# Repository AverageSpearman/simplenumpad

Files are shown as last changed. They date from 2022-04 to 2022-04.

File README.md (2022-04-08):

# simplenumpad
A very basic, hacked together mechanical numpad.

## Introduction

This was made with the goal of having a numpad to go with a mechanical keyboard lacking one.
Since I didn't want to bother with either buying a kit or going to a manufacturer to get a pcb, this is made using basically as few new parts as possible.
Most of the parts that aren't the electronics are just random garbage around the house.

## Parts List
Because this project doesn't use a PCB, all of the parts listed are through-hole components (THT).

|Part |Quantity |
|:--: |:---|
|Cherry MX Switches | 17 |
|1n4148 Diode | 17 |
|Arduino Pro Micro  | 1 |

That's pretty much it. You can even skip the diodes if you want to put in the anti-ghosting features in software. Stabilizers for the larger keys are optional.

## Layout
The layout is done in KiCad, but only because it's easy to get footprints for different kinds of mechanical switches, and print the design.
**The PCB design is used mainly as a wiring and layout guide. It is not meant to be manufactured and is not made to manufacturing specifications or common practice.**

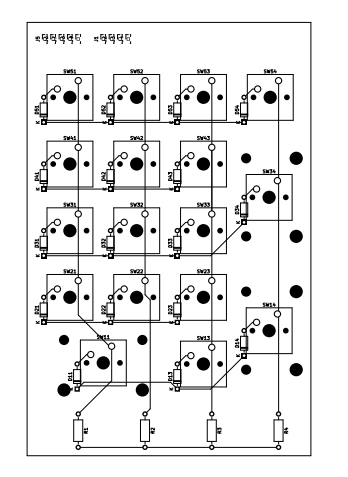
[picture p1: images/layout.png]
Printed Layout


## Assembly

### Circuit Board

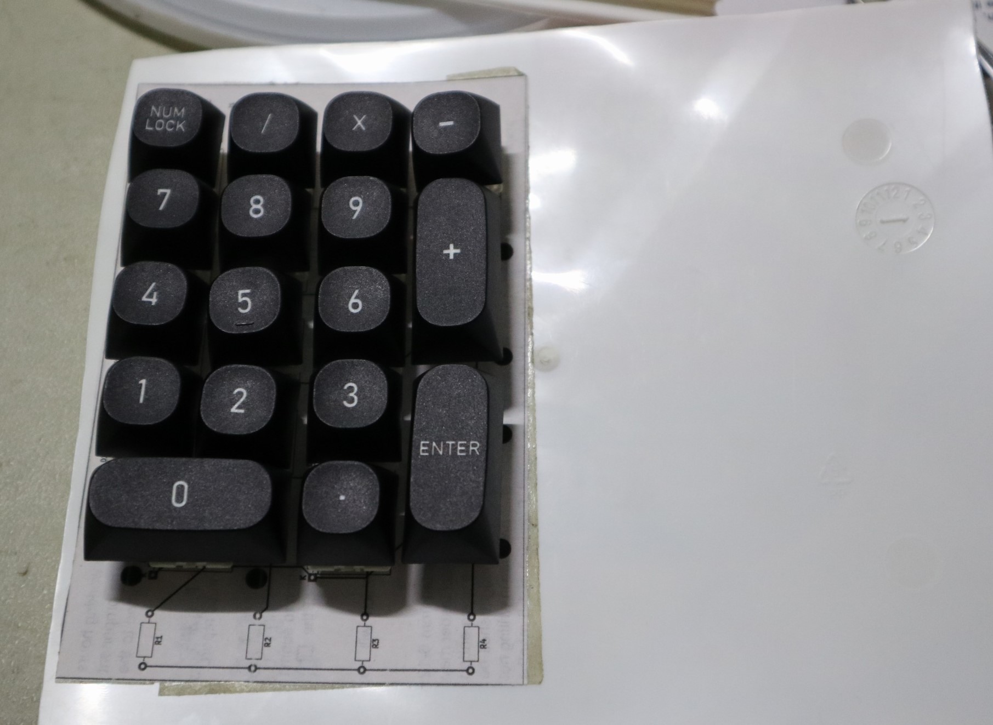
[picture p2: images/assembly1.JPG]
Switches and Caps in place


The first step is to punch, drill, or otherwise make the holes to mount the switches. You'll want to use PCB mount switches if you can, but I got away with plate-mounted switches, since they still at least have that big peg in the middle. These switches will more or less **be stuck where they are after the build, for the most part.** This *is* a really hacky, dirty way of doing it, but it is cheap. Jam the switches in, and then use hot glue or some other adhesive should you need it. You can put your keycaps on as well, if you want.

### Wiring

Use the schematic and layout as a guide when wiring the rows and columns. Make sure all of your diodes are facing the same direction (If you get them all backwards you should be able to fix it in software, but only if they're all backwards).

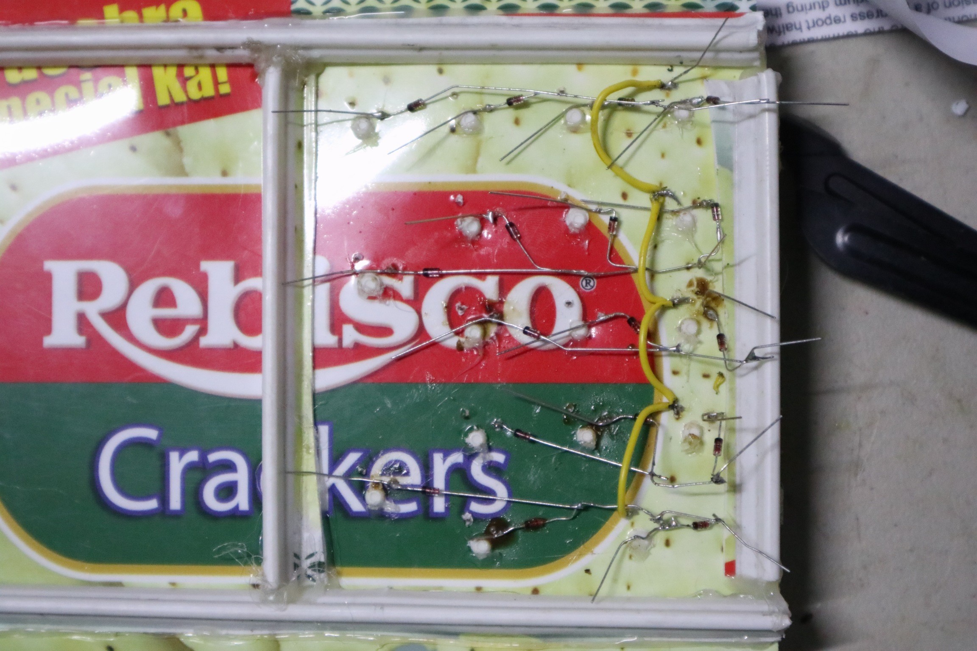
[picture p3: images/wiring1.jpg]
Wiring, the diode rows and one column

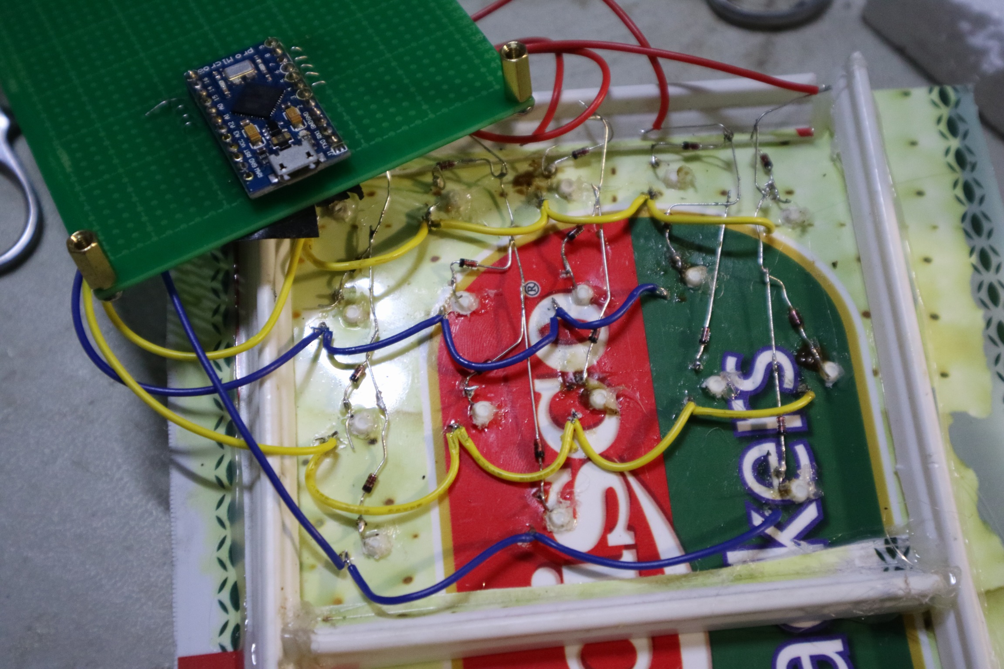
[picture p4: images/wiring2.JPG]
Wring, completed


## Code

This uses the SET library by RobTillaart ([Link](https://github.com/RobTillaart/SET)).
The code energizes columns and reads rows in a matrix, then puts them in sets and gets the difference to figure out which keys are newly pressed or released. The code will only press and release the keys as needed.

## Finished!

That's about it. Good luck!

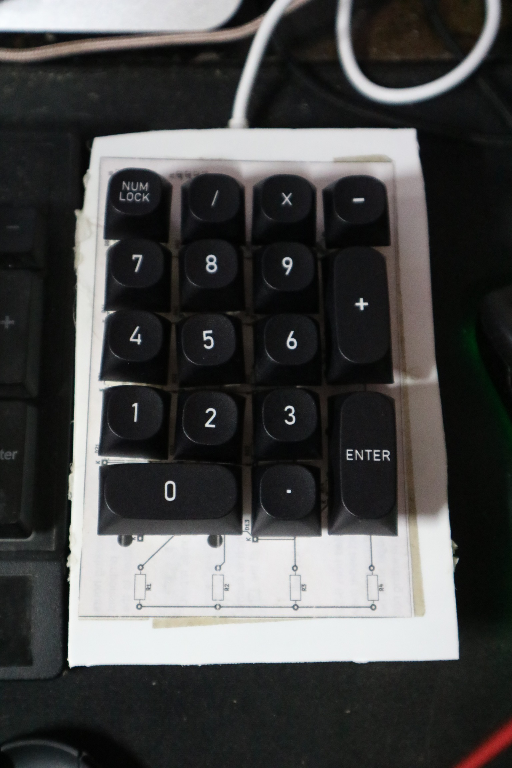
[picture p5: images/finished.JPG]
Finished numpad


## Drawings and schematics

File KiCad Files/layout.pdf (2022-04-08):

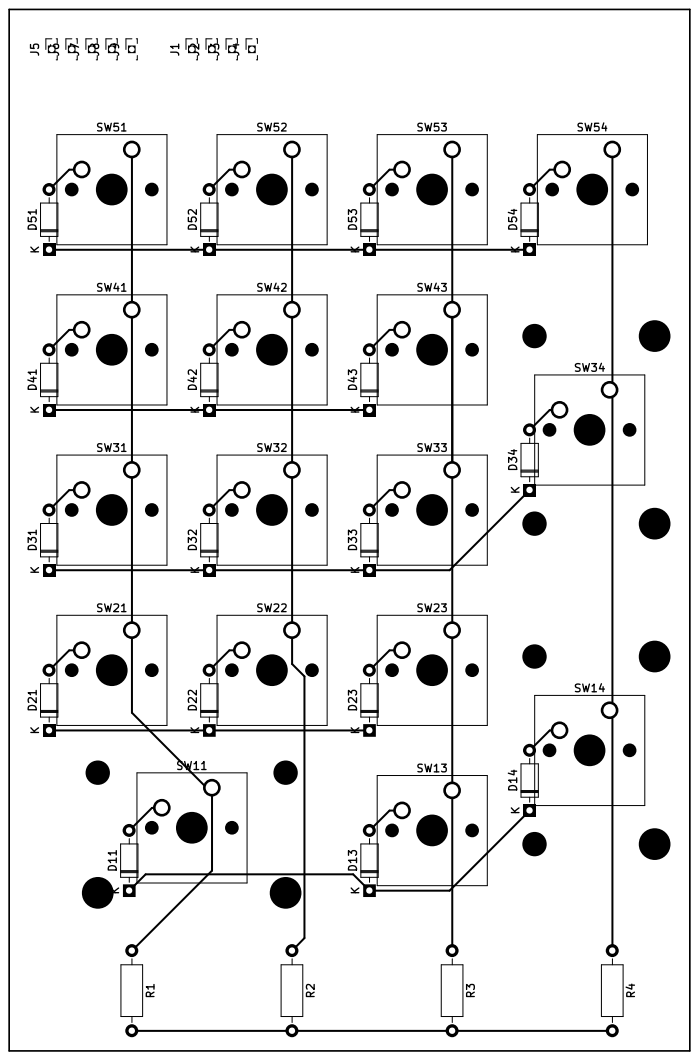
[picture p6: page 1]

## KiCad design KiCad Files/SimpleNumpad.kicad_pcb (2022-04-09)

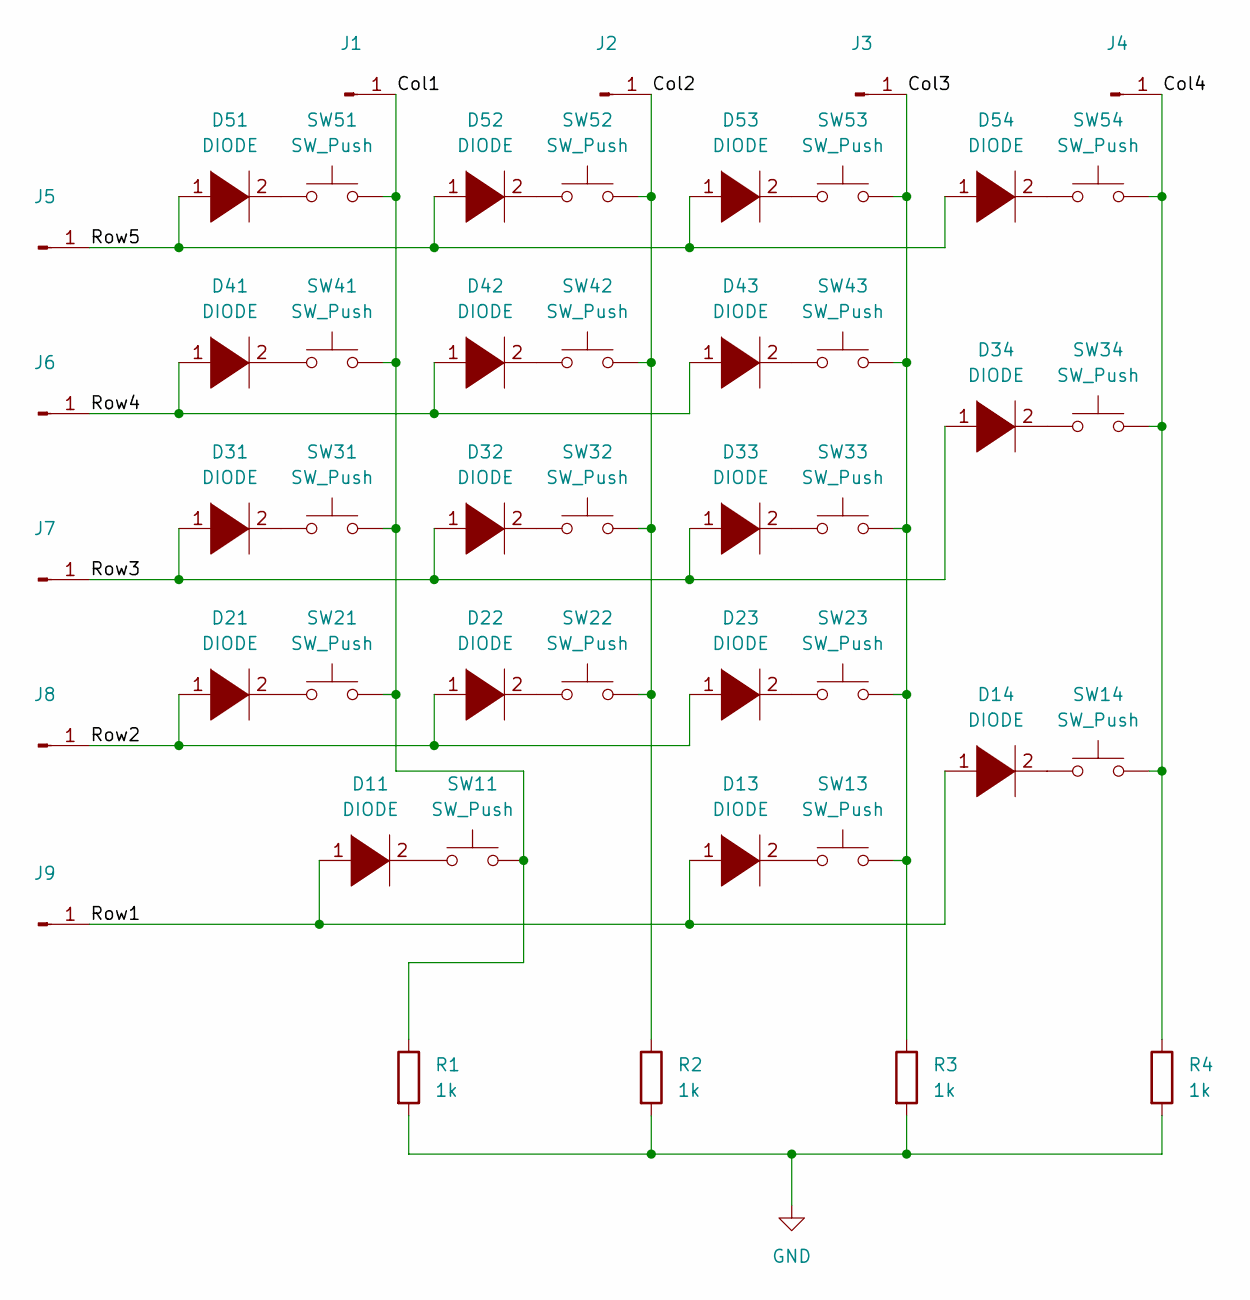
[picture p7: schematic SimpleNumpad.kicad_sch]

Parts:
D11, D13, D14, D21, D22, D23, D31, D32, D33, D34, D41, D42, D43, D51, D52, D53, D54: DIODE; D_DO-35_SOD27_P7.62mm_Horizontal
J1, J2, J3, J4, J5, J6, J7, J8, J9: (no value)
R1, R2, R3, R4: 1k; R_Axial_DIN0207_L6.3mm_D2.5mm_P10.16mm_Horizontal
SW11: SW_Push; SW_Cherry_MX_2.00u_PCB
SW13, SW21, SW22, SW23, SW31, SW32, SW33, SW41, SW42, SW43, SW51, SW52, SW53, SW54: SW_Push; SW_Cherry_MX_1.00u_PCB
SW14, SW34: SW_Push; SW_Cherry_MX_2.00u_Vertical_PCB

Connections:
/Col1: J1.1, R1.1, SW11.1, SW21.1, SW31.1, SW41.1, SW51.1
/Col2: J2.1, R2.1, SW22.1, SW32.1, SW42.1, SW52.1
/Col3: J3.1, R3.1, SW13.1, SW23.1, SW33.1, SW43.1, SW53.1
/Col4: J4.1, R4.1, SW14.1, SW34.1, SW54.1
/Row1: D11.1 (K), D13.1 (K), D14.1 (K), J9.1
/Row2: D21.1 (K), D22.1 (K), D23.1 (K), J8.1
/Row3: D31.1 (K), D32.1 (K), D33.1 (K), D34.1 (K), J7.1
/Row4: D41.1 (K), D42.1 (K), D43.1 (K), J6.1
/Row5: D51.1 (K), D52.1 (K), D53.1 (K), D54.1 (K), J5.1
GND: R1.2, R2.2, R3.2, R4.2
unnamed: D11.2 (A), SW11.2
unnamed: D13.2 (A), SW13.2
unnamed: D14.2 (A), SW14.2
unnamed: D21.2 (A), SW21.2
unnamed: D22.2 (A), SW22.2
unnamed: D23.2 (A), SW23.2
unnamed: D31.2 (A), SW31.2
unnamed: D32.2 (A), SW32.2
unnamed: D33.2 (A), SW33.2
unnamed: D34.2 (A), SW34.2
unnamed: D41.2 (A), SW41.2
unnamed: D42.2 (A), SW42.2
unnamed: D43.2 (A), SW43.2
unnamed: D51.2 (A), SW51.2
unnamed: D52.2 (A), SW52.2
unnamed: D53.2 (A), SW53.2
unnamed: D54.2 (A), SW54.2

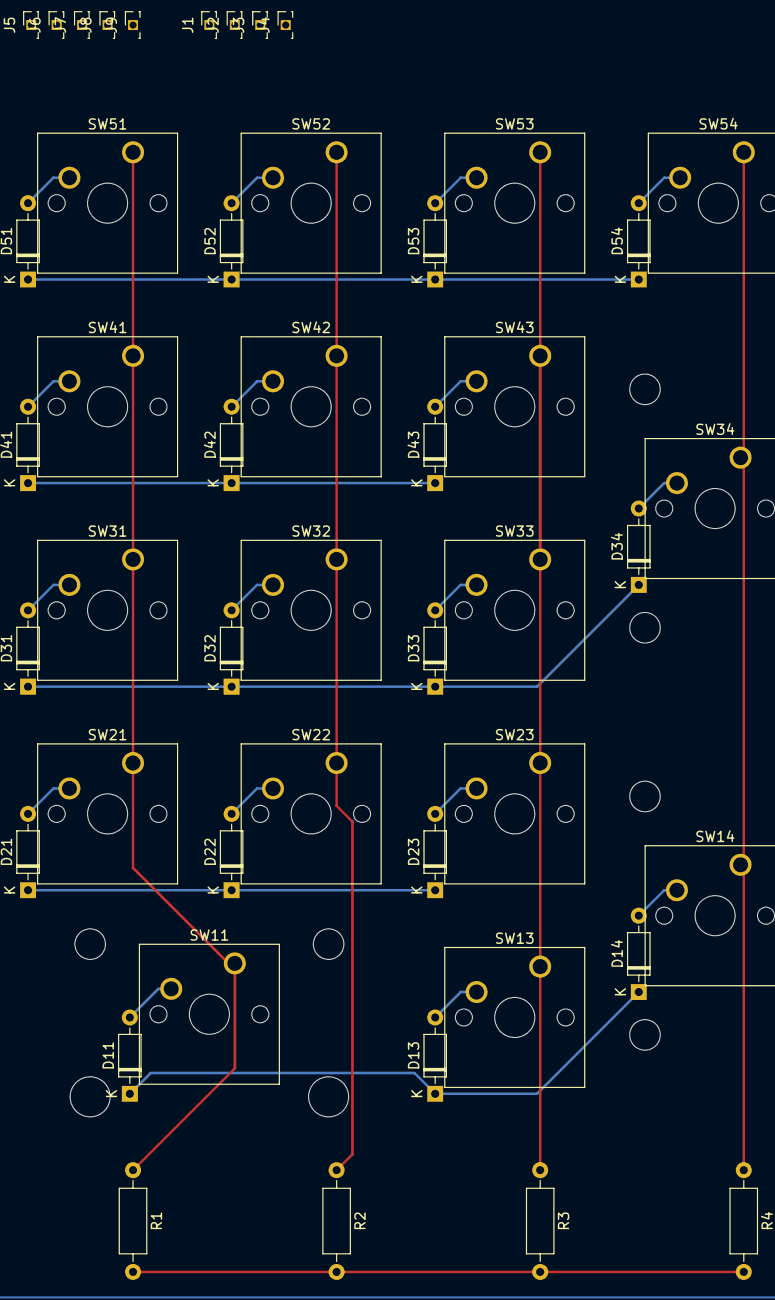
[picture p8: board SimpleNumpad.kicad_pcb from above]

Board: 2 copper layers, 47 parts (0 on the bottom side), 27 nets.

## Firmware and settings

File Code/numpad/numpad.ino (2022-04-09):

#include <set.h>

#include <Keyboard.h>
int row1 = 9;
int row2 = 8;
int row3 = 7;
int row4 = 6;
int row5 = 5;

int col1 = 15;
int col2 = 14;
int col3 = 16;
int col4 = 10;

int keypadPins[9] = {row1,row2,row3,row4,row5,col1,col2,col3,col4};
int keypadStatus[20];
int lastKeypadStatus[20];
Set keyPresses;
Set lastKeyPresses;

int waitRepeatCount = 10;
int curWaitCount = 0;
//char keyMatrix[20] = {'0', ',', '.', '\n',
//                      '1', '2', '3', ',',
//                      '4', '5', '6', ',',
//                      '7', '8', '9', '+',
//                      'L', '/', '*', '-'};

int keyMatrix[20] = {234, ',', 235, 224,
                      225, 226, 227, ',',
                      228, 229, 230, ',',
                      231, 232, 233, 223,
                      219, 220, 221, 222};
//Matrix
//[LCK  /   *   - ]
//[ 7   8   9   + ]
//[ 3   5   6   N ]
//[ 1   2   3   N ]
//[ 0   N   .  ENT]

//Val
//[LCK  /   *   - ]
//[ 7   8   9   + ]
//[ 3   5   6   N ]
//[ 1   2   3   N ]
//[ 0   N   .  ENT]

//220 '\334' Keypad / 
//221 '\335' Keypad * 
//222 '\336' Keypad - 
//223 '\337' Keypad + 
//224 '\340' Keypad ENTER 
//225 '\341' Keypad 1 and End 
//226 '\342' Keypad 2 and Down Arrow 
//227 '\343' Keypad 3 and PageDn 
//228 '\344' Keypad 4 and Left Arrow 
//229 '\345' Keypad 5 
//230 '\346' Keypad 6 and Right Arrow 
//231 '\347' Keypad 7 and Home 
//232 '\350' Keypad 8 and Up Arrow 
//233 '\351' Keypad 9 and PageUp 
//234 '\352' Keypad 0 and Insert /235 '\353' Keypad . and Delete
//219 Keypad Numlock
void setup() {
  Serial.begin(9600);
  // put your setup code here, to run once:
  for (int i=0; i<9; i++)
  {
    pinMode(keypadPins[i], INPUT);
    digitalWrite(keypadPins[i], LOW);
  }
}

void loop() {
  // put your main code here, to run repeatedly:
  getKeypadStatus();
  
  if(!array_cmp(keypadStatus, lastKeypadStatus, 20, 20)){
    curWaitCount = 0;
    //Keyboard.releaseAll();
    Serial.print("Keys changed:");
    keyPresses.clear();
    for(int i = 0; i < 20; i++){
      if(keypadStatus[i] < 1) break;
      keyPresses.add(keypadStatus[i]-1);
      Serial.print(keyMatrix[keypadStatus[i]-1]);
    }
    Set released = (lastKeyPresses - keyPresses);
    Set pressed = (keyPresses - lastKeyPresses );
    if(!pressed.isEmpty()) Keyboard.press(keyMatrix[pressed.first()]);
    if(!released.isEmpty()) Keyboard.release(keyMatrix[released.first()]);
    Serial.print(" ");
    Serial.print(released.count());
    Serial.print(" Released ");
    Serial.print(pressed.count());
    Serial.print(" Pressed ");
    
    Serial.print("\n");
    
  }
  
  
  array_copy(keypadStatus, lastKeypadStatus, 20, 20);  
  lastKeyPresses.clear();
  for(int i = 0; i < 20; i++){
    if(lastKeypadStatus[i] < 1) break;
    lastKeyPresses.add(lastKeypadStatus[i]-1);
  }
}

void getKeypadStatus()
{
  int rowPins[5] = {row1, row2, row3, row4, row5};  // row pins are 2, 7, 6, and 1 of the keypad
  int columnPins[4] = {col1, col2, col3, col4};  // column pins are pins 2, 4, and 5 of the keypad
  memset(keypadStatus, 0, sizeof(keypadStatus));
  int keypadIndex = 0;
  /* initialize all pins, inputs w/ pull-ups */
  for (int i=0; i<9; i++)
  {
    pinMode(keypadPins[i], INPUT);
    digitalWrite(keypadPins[i], HIGH);
  }
  
  for (int col=0; col<4; col++)
  {  // initial for loop to check all 4 cols
    pinMode(columnPins[col], OUTPUT);  // set the row pin as an output
    digitalWrite(columnPins[col], LOW);  // pull the row pins low
    for (int row=0; row<5; row++)
    {  // embedded for loop to check all 5 rows of each column
      if (!digitalRead(rowPins[row]))
      {
        int bitPos = ((row+1)*4 + (col+1) - 5)+1;
        //keypadStatus |= 1 << ((row+1)*4 + (col+1) - 5);  // set the status bit of the keypad return value
        keypadStatus[keypadIndex] = bitPos;  // set the status bit of the keypad return value
        keypadIndex++;
        if(keypadIndex == 20) keypadIndex = 0;
      }
    }
    pinMode(columnPins[col], INPUT);  // reset the row pin as an input
    digitalWrite(columnPins[col], HIGH);  // pull the row pin high
  }
}
void array_copy(int* a, int* b, int len_a, int len_b){
  int n;
  for(n = 0; n < len_a; n++) b[n] = a[n];
}
boolean array_cmp(int *a, int *b, int len_a, int len_b){
      int n;

      // if their lengths are different, return false
      if (len_a != len_b) return false;

      // test each element to be the same. if not, return false
      for (n=0;n<len_a;n++) if (a[n]!=b[n]) return false;

      //ok, if we have not returned yet, they are equal :)
      return true;
}
